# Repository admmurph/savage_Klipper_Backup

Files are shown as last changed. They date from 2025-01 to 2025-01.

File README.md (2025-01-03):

Backup for my Ender 3v2, currently mostly stock with a CR Touch w/stock metal bracket. Mostly small mods such as magnetic PEI plate, capricorn tube, and the mini satsana duct (remix) from thingiverse, with 0.6mm nozzle.

If you're setting up Klipper for the first time with an E3v2 4.2.2 Mainboard everything should be pretty dialed in. Can be adjusted for mostly any printer if you know what to change. Run a PID tune (see macros.cfg) for the bed,nozzle, as well as [input shaper] calibration, e-steps, and tune z offset (tune it, then tune current filament flow, then tune z offset again).
A few things should be changed/tuned in the slicer as well, i.e. pressure advance as well as retraction per filament. Included samples and links to useful tools and guides. See [firmware_retraction] and [extruder] pressure_advance in printer.cfg.

I highly recommend Orcaslicer (https://github.com/SoftFever/OrcaSlicer).

If you're setting up Klipper for the first time, use KIAUH (https://github.com/dw-0/kiauh). Very straightforward.

# Klipper-Backup 💾 

Klipper backup script for manual or automated GitHub backups. This backup is for Klipper+Moonraker, with Mainsail interface.

This backup is provided by [Klipper-Backup](https://github.com/Staubgeborener/klipper-backup).

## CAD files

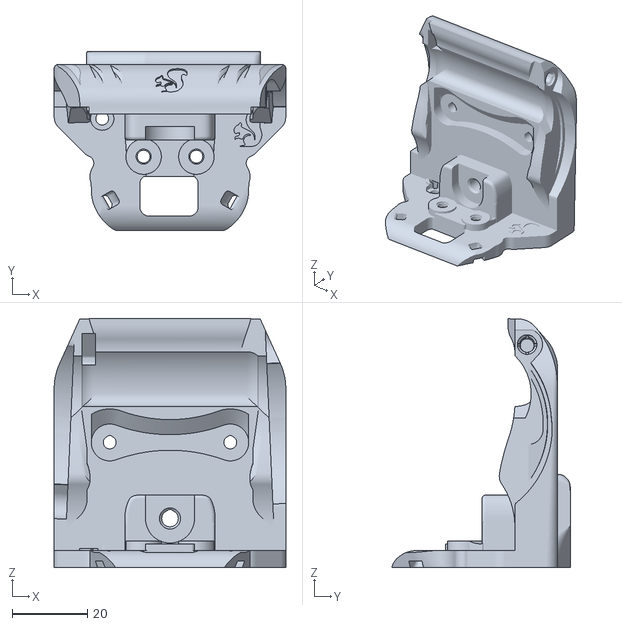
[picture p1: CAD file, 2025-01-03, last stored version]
printer_upgrades/ducts/apollo/Orbiter 2.x - front motor - Creality - stock MK8.stl
61.5 x 47.4 x 66.1

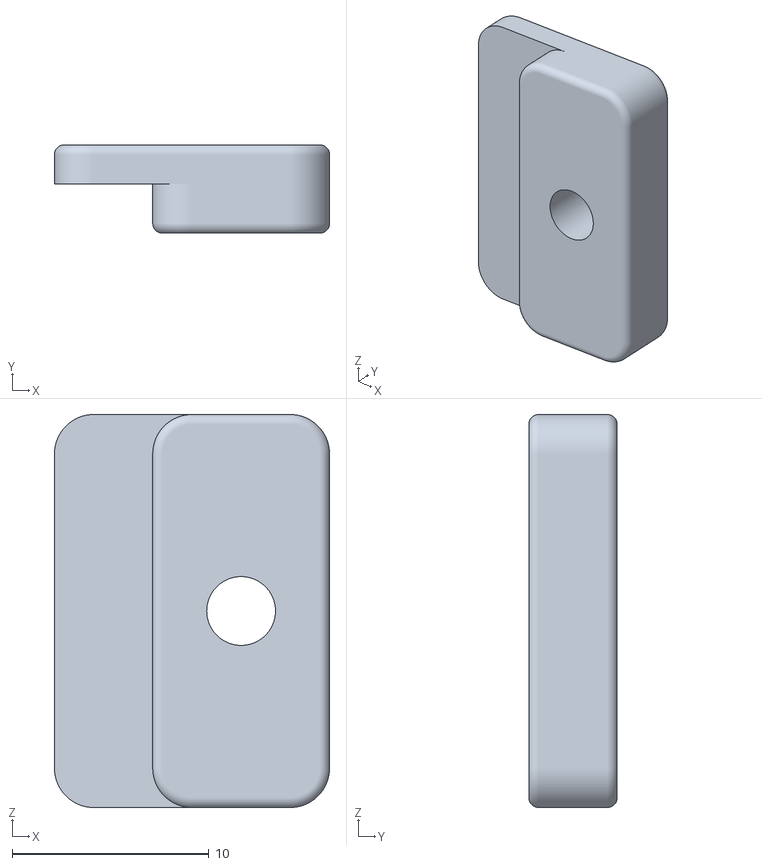
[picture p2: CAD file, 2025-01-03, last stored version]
printer_upgrades/ducts/MiniSatsana1x4010/mini_Satsana_Clamp.stl
14.0 x 4.50 x 20.0

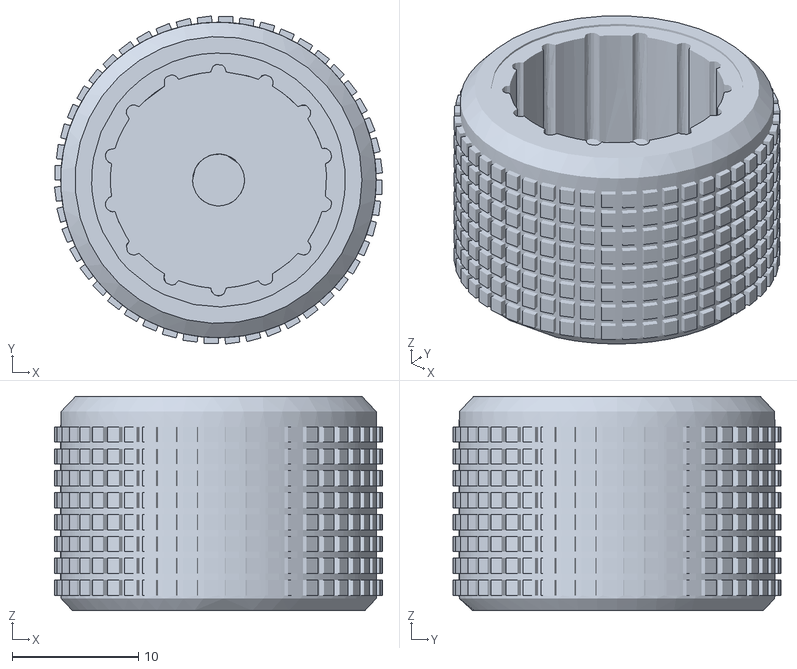
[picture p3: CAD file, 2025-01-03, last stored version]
printer_upgrades/extras/Knob_Belt_Tension_Covers.stl
26.0 x 26.0 x 17.0

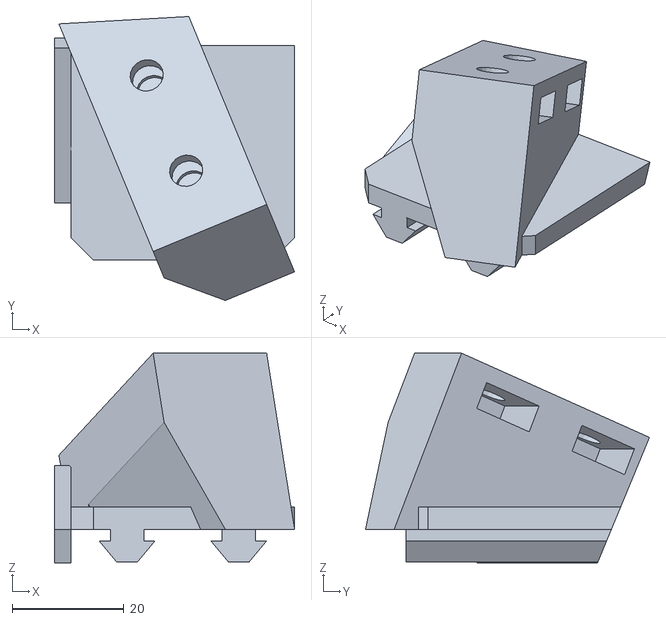
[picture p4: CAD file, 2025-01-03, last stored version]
printer_upgrades/filament_holders/Rear_angle_spool_holder.stl
43.0 x 50.8 x 37.5

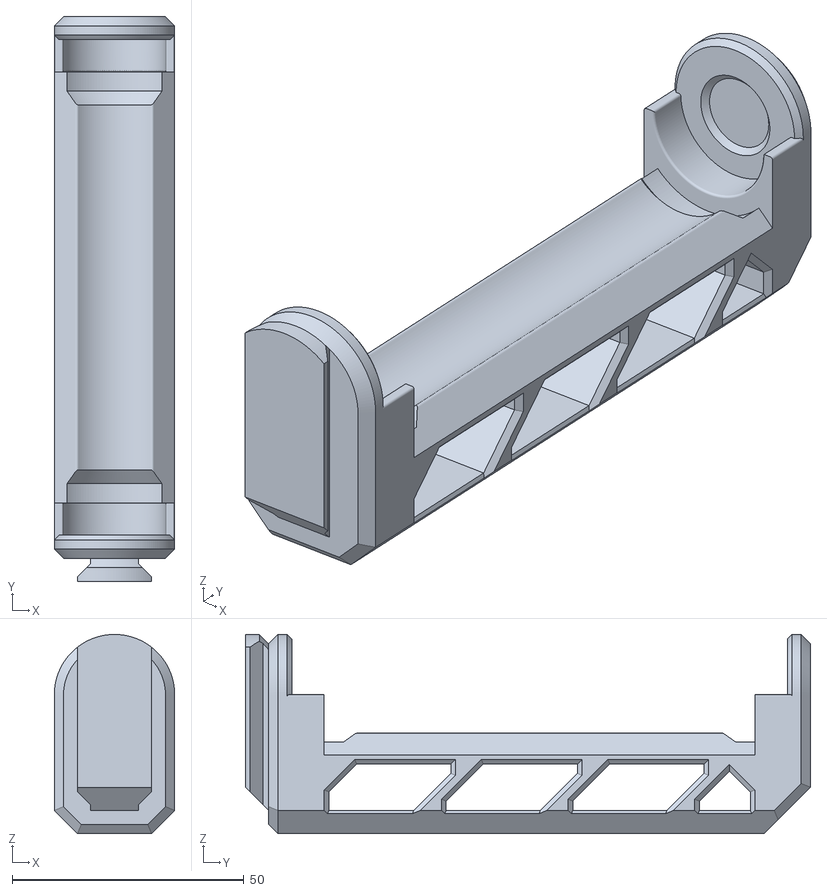
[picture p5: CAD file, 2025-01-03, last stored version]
printer_upgrades/filament_holders/Roller/Body_80mm.stl
26.0 x 122.0 x 43.0

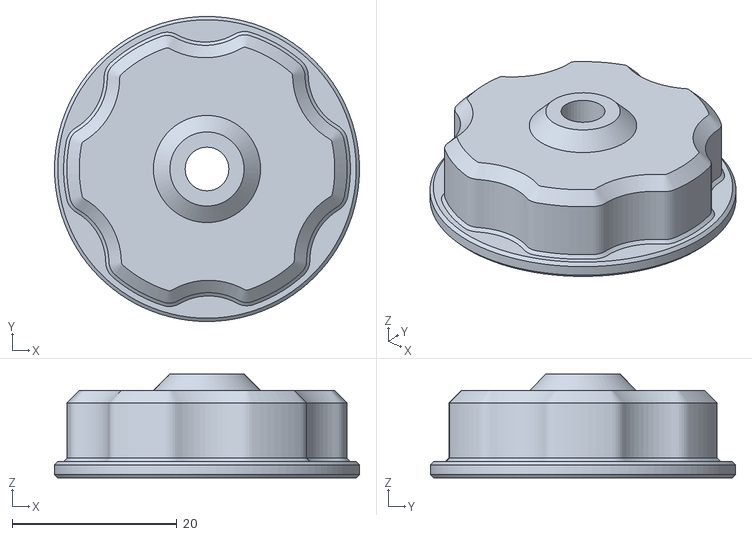
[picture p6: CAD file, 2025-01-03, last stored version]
printer_upgrades/kevinakasam_singleMotorBeltedZ/1_TensionerRing_V3.6.stl
37.0 x 37.0 x 12.6

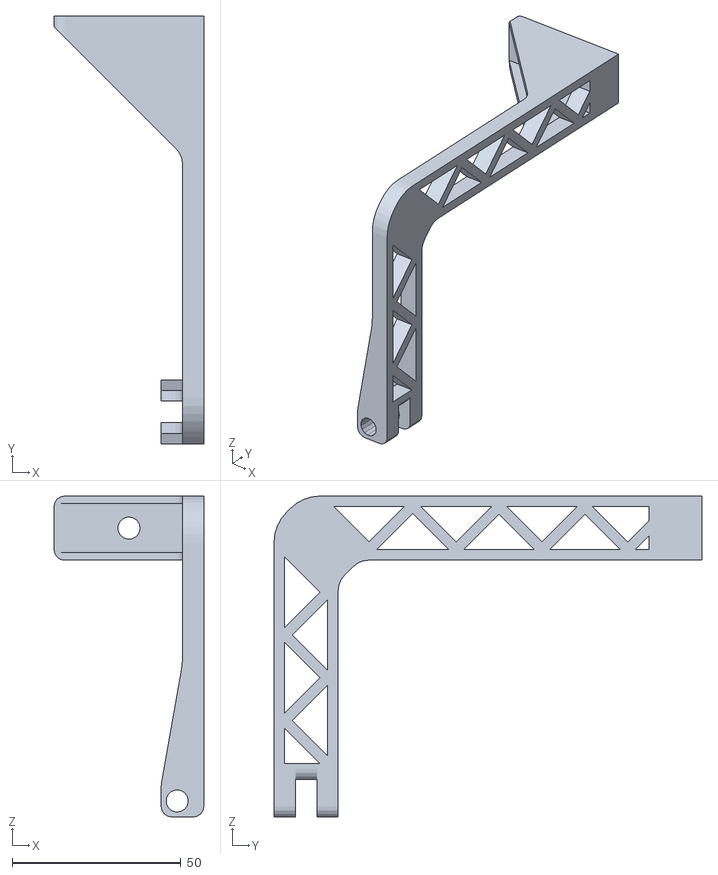
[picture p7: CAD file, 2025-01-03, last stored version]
printer_upgrades/m5_webcam_arms/Ender_3_Webcam_Arm_v2.stl
44.4 x 127.0 x 95.2

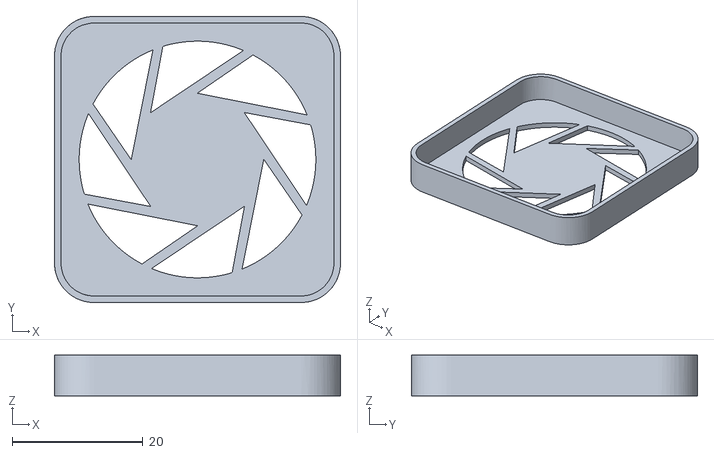
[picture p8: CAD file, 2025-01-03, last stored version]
printer_upgrades/qr_covers/Aperature_Science_Ender_3_Cover.stl
43.7 x 43.7 x 6.20

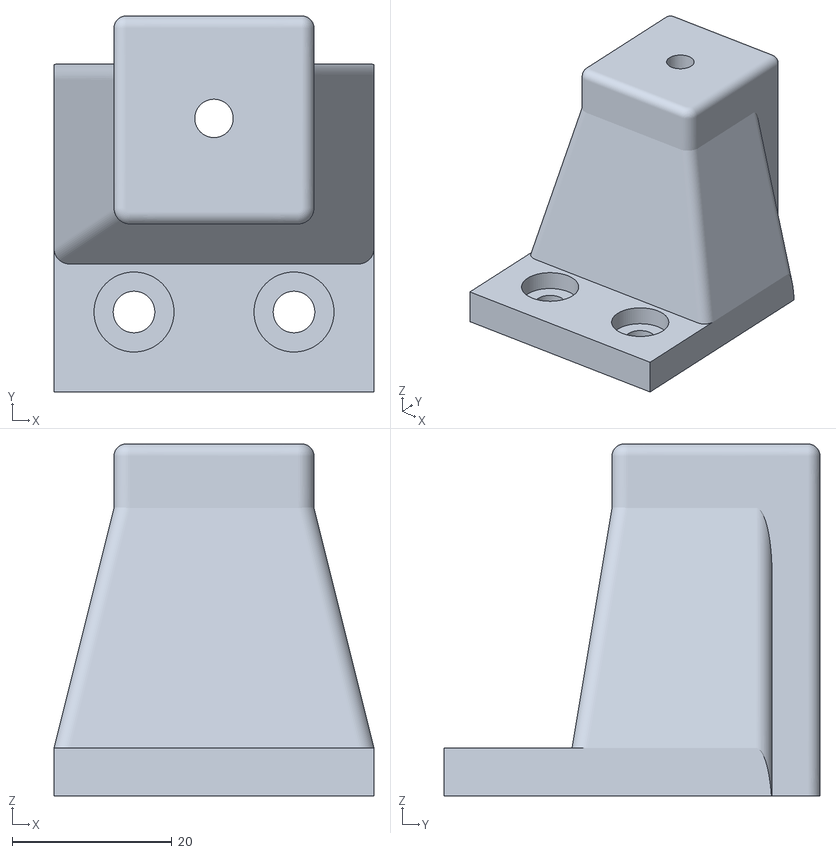
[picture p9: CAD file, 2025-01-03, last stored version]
printer_upgrades/replacement_parts/Ender3_V2_belt_tensionerY.stl
40.0 x 47.0 x 44.0

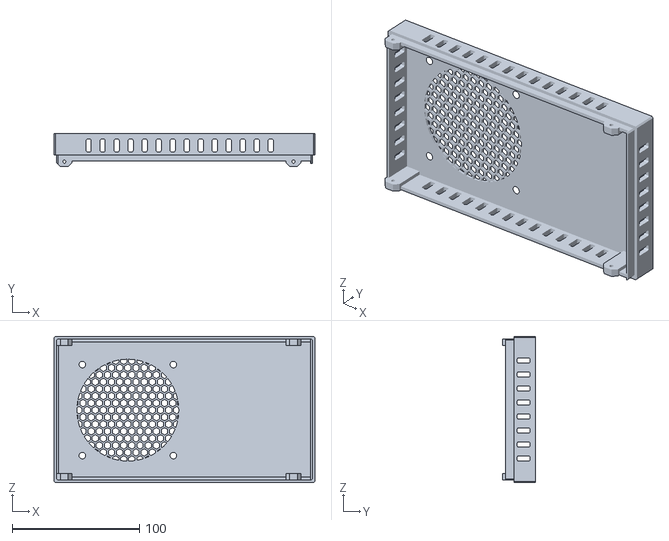
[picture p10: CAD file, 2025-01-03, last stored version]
printer_upgrades/undercarriage/PSU_cover_slim.stl
205.0 x 26.1 x 115.0

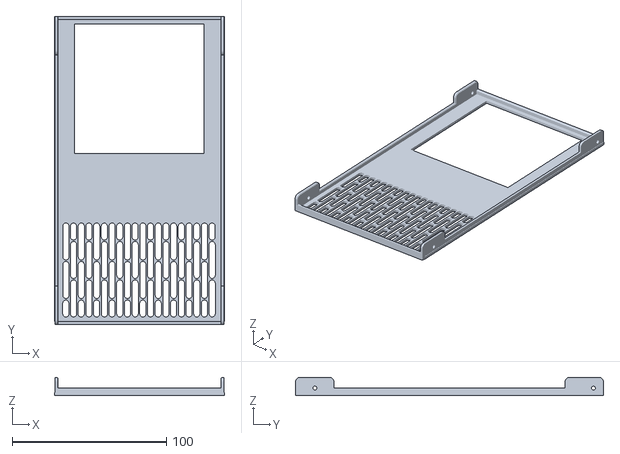
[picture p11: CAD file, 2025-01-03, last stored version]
printer_upgrades/undercarriage/slim80mm psu/Plaque.stl
110.6 x 200.0 x 12.0

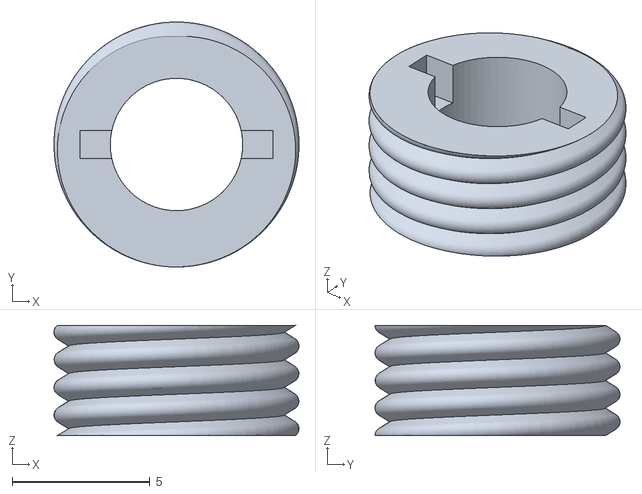
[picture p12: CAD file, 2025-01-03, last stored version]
printer_upgrades/ducts/apollo/Stock hotend cable guide.stl
8.88 x 8.88 x 4.00

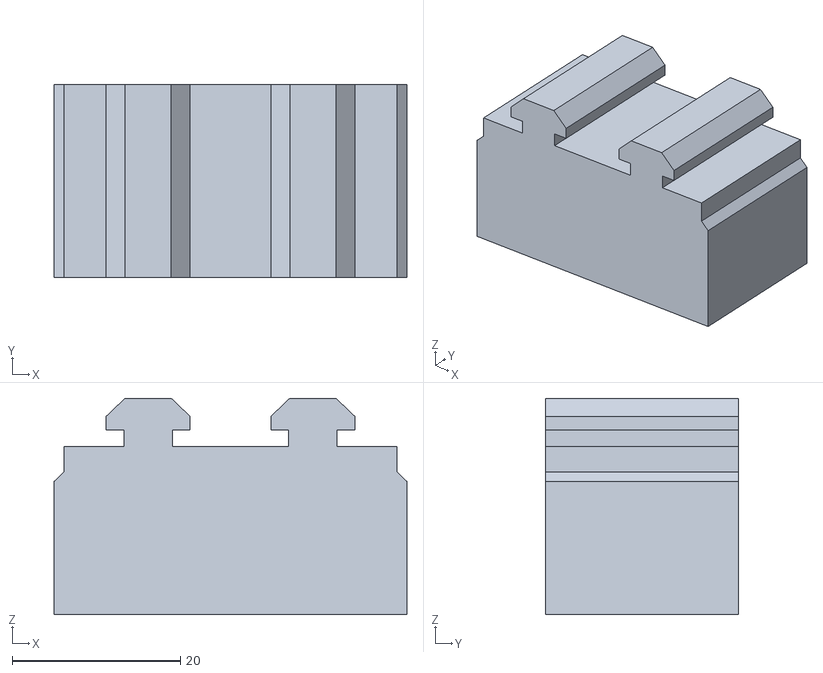
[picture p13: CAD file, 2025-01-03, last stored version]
printer_upgrades/extras/Feet_Riser_Solid.STL
42.0 x 23.0 x 25.8

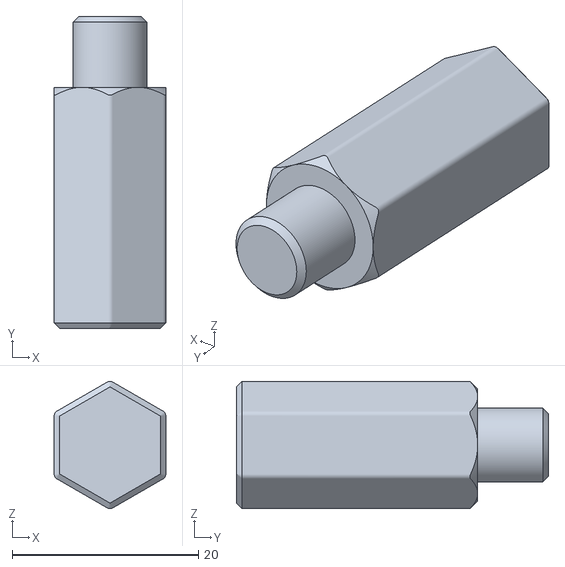
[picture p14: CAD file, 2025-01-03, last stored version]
printer_upgrades/filament_holders/Roller/Pin.stl
12.0 x 33.5 x 13.7

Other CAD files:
printer_upgrades/kevinakasam_singleMotorBeltedZ/2_Bottom_F623_V3.7.stl
printer_upgrades/m5_webcam_arms/Ender_3_Webcam_Base_v2.stl
printer_upgrades/qr_covers/Back_plate.stl
printer_upgrades/replacement_parts/Ender3_V2_belt_tensionerX.stl
printer_upgrades/ducts/apollo/CRtouch - baseline.stl
printer_upgrades/ducts/apollo/Orbiter 1.5 - Creality - stock MK8.stl
printer_upgrades/ducts/apollo/bowden adapter - orbiter 2 rear motor backplate.stl
printer_upgrades/ducts/apollo/left duct - baseline.stl
printer_upgrades/ducts/apollo/right duct - baseline.stl
printer_upgrades/extras/Ender 3 bed leveling wheel clips v2 thicker arms.stl
printer_upgrades/extras/Ender 3 bed leveling wheel clips v2 thicker armsflipped.stl
printer_upgrades/extras/MinimalBedHandle.stl
printer_upgrades/extras/chungy_knob.stl
printer_upgrades/filament_holders/Roller/Body_100mm.stl
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

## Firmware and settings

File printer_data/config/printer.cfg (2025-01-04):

[include mainsail.cfg]
[include macros.cfg]
[include KAMP_Settings.cfg] # adaptive purge
[include shell_command.cfg]
[exclude_object]
# See docs/Config_Reference.md for a description of parameters.
# 
# <---------------------- Ender 3v2 Config File ----------------------> #
# # by Adam Murphy
[printer]
kinematics: cartesian
max_velocity: 300
max_accel: 3000
max_accel_to_decel: 3000
max_z_velocity: 5
max_z_accel: 100
square_corner_velocity: 5

[heater_bed]
heater_pin: PA2
sensor_type: EPCOS 100K B57560G104F
sensor_pin: PC4
# Tuned for stock hardware with 50 degree Celsius target <- See macros.cfg
# control = pid
# pid_kp = 71.013
# pid_ki = 1.466
# pid_kd = 860.140
min_temp: 0
max_temp: 120

[extruder]
step_pin: PB4
dir_pin: PB3
enable_pin: !PC3
microsteps: 16
max_extrude_only_distance: 100.0 
rotation_distance: 33.1 # [https://ellis3dp.com/Print-Tuning-Guide/articles/extruder_calibration.html#steps]
nozzle_diameter: 0.400  # Change to current nozzle size!! <----
filament_diameter: 1.750
pressure_advance: 0.104 # See [firmware_retraction for per-filament example]
heater_pin: PA1
#   Stock hotend:
#sensor_type: EPCOS 100K B57560G104F
#   High Speed Print Head Upgrade Hotend Kit For 
#   Ender 3/CR10/VORON 2.4 Hi-End Extruder J-head:
sensor_type: Generic 3950
#   link: https://www.aliexpress.us/item/3256807991597019
sensor_pin: PC5
min_temp: 0
max_temp: 270
#control = pid #tuned for stock hotend @ 210°C
# pid_kp = 25.649
# pid_ki = 1.276
# pid_kd = 128.886
max_extrude_cross_section: 5 # Setting for KAMP Adaptive Purge

[firmware_retraction]
#   "Highlight + CTRL+/" to comment out if using slicer retraction
retract_length: 2
#   The length of filament (in mm) to retract when G10 is activated,
#   and to unretract when G11 is activated (but see
#   unretract_extra_length below). The default is 2 mm.
#   Very conservative value, accounting for pressure advance.
retract_speed: 30
#   The speed of retraction, in mm/s. The default is 30 mm/s.
unretract_extra_length: 0
#   The length (in mm) of *additional* filament to add when
#   unretracting.
unretract_speed: 40
#   The speed of unretraction, in mm/s. The default is 40 mm/s.
#
#   Retraction Test 
#   (Use the Orcaslicer Calibration tool. Adapt this command to the settings used):
#
#   TUNING_TOWER COMMAND=SET_RETRACTION PARAMETER=RETRACT_LENGTH START=0 FACTOR=0.1
#
#   Slicer filament gcode example:
#
# ; filament start gcode
# SET_PRESSURE_ADVANCE ADVANCE=?
# SET_RETRACTION RETRACT_LENGTH=? RETRACT_SPEED=? UNRETRACT_SPEED=? ;doesn't produce console response :(
# RESPOND MSG="retract_length: 0.0 | retract_speed: 0.0 | unretract_speed: 0.0"
# RESPOND MSG="...Printing with ?Color & Type? - ?Brand & Characteristics?" ; i.e. Black Rapid PETG - Elegoo Glossy 
#

[input_shaper]
shaper_freq_x:49.0196078431
shaper_freq_y:54.5851528384
#shaper_type: mvz
#  For testing: [https://www.klipper3d.org/Resonance_Compensation.html]
#  Will set up ADXL345 tuning soon, may be on another fork (if viewed later). 

# <---------------------- CR_Touch Config ----------------------> #
# This entire section can be removed/commented out (Highlight + CTRL+/) if using stock Z-endstop #

[bltouch]
sensor_pin: ^PB1  # This is unique to your mainboard
control_pin: PB0  # This is unique to your mainboard
x_offset: -51.6   # This may need to be calibrated
y_offset: -12.5      # This may need to be calibrated
#z_offset: 1.100   # Tune value 
# [https://ellis3dp.com/Print-Tuning-Guide/articles/first_layer_squish.html]
samples: 2       
speed: 2          

[safe_z_home] 
# Change coordinates to the center of your print bed (ATLEAST values larger than probe offset!!)
home_xy_position: 117, 100  # Nozzle is pretty centered 
speed: 70                   # Turn this down if z-offset isn't dialed in
z_hop: 10                   # Move up 10mm
z_hop_speed: 10             #

[bed_mesh] # Adaptive mesh enabled; EXCLUDE OBJECTS must be turned on in slicer!
# See [gcode_macro START_PRINT] in macros.cfg to enable/disable
# [https://www.klipper3d.org/Bed_Mesh.html]
# [https://www.klipper3d.org/Exclude_Object.html]
speed: 150
horizontal_move_z: 6
mesh_min: 20, 6       # These are fairly safe min/max values, 
mesh_max: 195.5, 207  # glass bed w/ metal clips should have no issue
probe_count: 5,5
mesh_pps: 2,2
fade_start: 1
fade_end: 10    # Stop using the bed mesh by z=10
fade_target: 0
adaptive_margin: 5

[screws_tilt_adjust]
# Easiest way to level the bed
# Values are for Ender 3v2 with CrTouch/w included steel bracket.
# [https://www.klipper3d.org/Manual_Level.html?h=z+endstop+c#adjusting-bed-leveling-screws-using-the-bed-probe]
screw1: 74, 199.5
screw1_name: rear left screw # Base screw
screw2: 74, 31.5
screw2_name: front left screw
screw3: 243,31.5
screw3_name: front right screw
screw4: 243,199.5
screw4_name: rear right screw
horizontal_move_z: 10
speed: 150
screw_thread: CW-M4

# Install with KIAUH or comment out:
[include moonraker_obico_macros.cfg]
# Black magic free web monitoring of printer. Free AI print failure detection. Free live webcam view. Useful but ?

# <---------------------- Stepper-Mainboard Config ----------------------> #
# Pretty much stock config (w/ less conservative x&y min/max values) + CR Touch
# This file contains pin mappings for the stock 2020 Creality Ender 3
# V2. To use this config, during "make menuconfig" select the
# STM32F103 with a "28KiB bootloader" and serial (on USART1 PA10/PA9)
# communication.

# If you prefer a direct serial connection, in "make menuconfig"
# select "Enable extra low-level configuration options" and select
# serial (on USART3 PB11/PB10), which is broken out on the 10 pin IDC
# cable used for the LCD module as follows:
# 3: Tx, 4: Rx, 9: GND, 10: VCC

# Flash this firmware by copying "out/klipper.bin" to a SD card and
# turning on the printer with the card inserted. The firmware
# filename must end in ".bin" and must not match the last filename
# that was flashed.

[mcu]
serial: /dev/serial/by-id/usb-1a86_USB_Serial-if00-port0
restart_method: command

[fan]
pin: PA0

[stepper_x]
step_pin: PC2
dir_pin: PB9
enable_pin: !PC3
microsteps: 16
rotation_distance: 40
endstop_pin: ^PA5
position_endstop: 0
position_min: -15
position_max: 245
homing_speed: 50

[stepper_y]
step_pin: PB8
dir_pin: PB7
enable_pin: !PC3
microsteps: 16
rotation_distance: 40
endstop_pin: ^PA6
position_endstop: 0
position_min: -13
position_max: 230
homing_speed: 50

[stepper_z]
step_pin: PB6
dir_pin: !PB5
enable_pin: !PC3
microsteps: 16
rotation_distance: 8
endstop_pin: probe:z_virtual_endstop
#position_endstop: 0.0 # CR TOUCH
position_max: 250
position_min: -6

# <---------------------- No need to edit ----------------------> #
[idle_timeout]
#   Idle time (in seconds) to wait before running the above G-Code
#   commands. The default is 600 seconds. Set via macros.cfg START_PRINT, PREHEAT and DRY_FILAMENT

[gcode_arcs]
resolution: 0.25 #lolz
#   An arc will be split into segments. Each segment's length will
#   equal the resolution in mm set above. Lower values will produce a
#   finer arc, but also more work for your machine. Arcs smaller than
#   the configured value will become straight lines. The default is
#   1mm.

# VVVV Automatic | Delete if having issues VVVV

#*# <---------------------- SAVE_CONFIG ---------------------->
#*# DO NOT EDIT THIS BLOCK OR BELOW. The contents are auto-generated.
#*#
#*# [heater_bed]
#*# control = pid
#*# pid_kp = 71.013
#*# pid_ki = 1.466
#*# pid_kd = 860.140
#*#
#*# [extruder]
#*# control = pid
#*# pid_kp = 36.670
#*# pid_ki = 14.380
#*# pid_kd = 23.377
#*#
#*# [bltouch]
#*# z_offset = 1.205

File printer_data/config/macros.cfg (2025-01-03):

[gcode_macro START_PRINT]
gcode:
# Orcaslicer start print machine g-code (activates this macro):
# START_PRINT BED_TEMP=[bed_temperature_initial_layer_single] EXTRUDER_TEMP=[nozzle_temperature_initial_layer] CHAMBER_TEMP=[chamber_temperature] #KEEP ALL ON ONE LINE!
#
  SET_IDLE_TIMEOUT TIMEOUT=1200
  TURN_OFF_HEATERS
  # Get first-layer bed-temp from slicer (Orca: [bed_temperature_initial_layer_single])
  {% set BED_TEMP = params.BED_TEMP|default(55)|float %}
  # Get first-layer extruder-temp from slicer (Orca: [nozzle_temperature_initial_layer])
  {% set EXTRUDER_TEMP = params.EXTRUDER_TEMP|default(190)|float %}
  M104 S{150} ; set nozzle warmup temp
  M140 S{BED_TEMP} ; wait for bed temp to create mesh
  RESPOND MSG="Homing and waiting for bed to reach temperature"
  G28 #home all
  M190 S{BED_TEMP} ; wait for bed temp to create mesh
  RESPOND MSG="Creating adaptive bed mesh"
  M104 S{EXTRUDER_TEMP} ; warmup while creating adaptive mesh
  BED_MESH_CALIBRATE PROFILE=currPrint Adaptive=1 Adaptive_Margin=5 PROBE_COUNT=4
  BED_MESH_PROFILE SAVE=currPrint
  BED_MESH_PROFILE LOAD=currPrint
  RESPOND MSG="Waiting for nozzle to reach temp... then drawing prime line"
  M109 S{EXTRUDER_TEMP} ; wait for temp to purge
  LINE_PURGE # purge nozzle
  RESPOND MSG="Print started!"
  
[gcode_macro END_PRINT]
gcode: 
# Orcaslicer end print machine g-code (activates this macro):
# ;Present model
# {if max_layer_z < printable_height}G1 Z{min(max_layer_z+2, printable_height)} F600 ; Move print head up{endif} 
# G1 X5 Y{print_bed_max[1]*0.8} F{travel_speed*60} ; present print
# {if max_layer_z < printable_height-10}G1 Z{min(max_layer_z+70, printable_height-10)} F600 ; Move print head further up{endif}
# {if max_layer_z < printable_height*0.6}G1 Z{printable_height*0.6} F600 ; Move print head further up{endif}
# END_PRINT
#
  M83 ; set to relative
  TURN_OFF_HEATERS
  M84 X Y E ; disable motors
  RESPOND MSG="Print complete!"

[gcode_macro CANCEL_PRINT]
gcode: 
  M83 ; set to relative
  TURN_OFF_HEATERS
  # Move nozzle away from print while retracting
  G91
  G1 X-2 Y-2 E-3 F300    # Raise nozzle by 25mm
  G1 Z25 F3000
  G90
  M84 X Y E ; disable motors
  RESPOND MSG="Print canceled!"
    
[gcode_macro PREHEAT_FILAMENT]
description: Preheats extruder and bed for PLA printing, extruder set to 150 to prevent filament leaking while homing etc
gcode:
  {% set EXTRUDER_TEMP = nozzle_temperature_initial_layer|default(150)|float %}
  {% set BED_TEMP = bed_temperature_initial_layer_single|default(60)|float %}
  M104 S{EXTRUDER_TEMP}
  M140 S{BED_TEMP}
  SET_IDLE_TIMEOUT TIMEOUT = 1200

[gcode_macro DRY_FILAMENT]
description: Allows for the heated print bed to act as an active dry box. Idle timeout 8hrs | PLA = 40-50 TPU 40-45 PETG = 60-65 ABS = 80 ASA = 80-85 NYLON = 85-90
gcode: 
  SET_IDLE_TIMEOUT TIMEOUT=28800 # 8 hour timeout
  TURN_OFF_HEATERS
  {%set BED_TEMP = params.BED_TEMP|default(40)|int %}
  M140 S{BED_TEMP}

[gcode_macro UNLOAD_FILAMENT]
description: Unloads Filament from extruder
gcode:
  {% if printer.extruder.temperature < 180 %}
    {action_respond_info("Extruder temperature too low")}
  {% else %}
    SAVE_GCODE_STATE NAME=UNLOAD_state
    {% set Z = params.Z|default(50)|int %}
    {% set axis_max = printer.toolhead.axis_maximum %}
    {% set pos = printer.toolhead.position %}
 
    {% set z_diff = axis_max.z - pos.z %}
    {% set z_safe_lift = [ Z, z_diff ] | min%}
 
    G91                   # relative positioning
    G0 Z{ z_safe_lift }
    # Reset extruder position
    G92 E0
    G1 E5.0 F300        # extrude a little
    G1 E-50 F{ 10 * 60 } # perform the unload
    G1 E-50 F{ 5 * 60 }   # finish the unload
    RESTORE_GCODE_STATE NAME=UNLOAD_state
  {% endif %}
  
# Good way to activate SCREWS_TILT_CALCULATE
  
[gcode_macro BED_TRAMMING_1]
description: Heats bed and starts process to level the bed with the screws
gcode:
  {% set BED_TEMP = params.BED_TEMP|default(60)|float %} 
  SET_HEATER_TEMPERATURE HEATER=heater_bed TARGET={BED_TEMP}
  HOME_CHECK
  M190 S{BED_TEMP}
  SCREWS_TILT_CALCULATE
  
[gcode_macro BED_TRAMMING_2]
description: Continues the bed screw leveling process (already heated)
gcode:
  SCREWS_TILT_CALCULATE

[gcode_macro G28]
# Only home if needed.
rename_existing: G28.1
gcode:
    {% if printer.toolhead.homed_axes != "xyz" %}
        G28.1
    {% endif %}

# Share variables between macros (Found this in someones macro.cfg but I don't really have a use for it yet)
# can be accessed via {printer["gcode_macro SHARE_VARIABLES"].VARIABLE_NAME}
# can be set with SET_GCODE_VARIABLE MACRO=SHARE_VARIABLES VARIABLE=VARIABLE_NAME VALUE=NEW_VALUE
[gcode_macro SHARE_VARIABLES]
variable_enable_save_config : False
variable_dim_enclosure_led : False
gcode:
#

#####################################
#          PID Tune Macros          #
#       Version 1.0  2023-1-30      #
#####################################

################################
######### PID_EXTRUDER #########
################################
[gcode_macro PID_EXTRUDER]
description: PID Tune for the Extruder
gcode:
  {% set e = printer.toolhead.extruder %}
  {% set T = params.TEMPERATURE|default(210)|float %}
  {% set S = params.FAN_IN_PERCENT|default(0)|float *2.55 %}
  {% set P = printer.configfile.config[e].pid_kp|float %}
  {% set I = printer.configfile.config[e].pid_ki|float %}
  {% set D = printer.configfile.config[e].pid_kd|float %}
  M106 S{S}
  M118 // PID parameters: pid_Kp={P} pid_Ki={I} pid_Kd={D}  (old)
  PID_CALIBRATE HEATER={e} TARGET={T}
  TURN_OFF_HEATERS
  SAVE_CONFIG
 
################################
############ PID_BED ###########
################################
[gcode_macro PID_BED]
description: PID Tune for the Bed
gcode:
  {% set T = params.TEMPERATURE|default(60)|float %}
  {% set P = printer.configfile.config['heater_bed'].pid_kp|float %}
  {% set I = printer.configfile.config['heater_bed'].pid_ki|float %}
  {% set D = printer.configfile.config['heater_bed'].pid_kd|float %}
  M118 // PID parameters: pid_Kp={P} pid_Ki={I} pid_Kd={D}  (old)
  PID_CALIBRATE HEATER=heater_bed TARGET={T}
  TURN_OFF_HEATERS
  SAVE_CONFIG

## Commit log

2024-12-27 New Backup on boot - 26/12/24 - 23:35:35
    [KAMP_Settings.cfg, macros.cfg, moonraker-obico-update.cfg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]
2024-12-27 printer.cfg modified - 27/12/24 - 00:09:57
    [printer.cfg]
2024-12-27 printer.cfg modified - 27/12/24 - 00:13:59
    [printer.cfg]
2024-12-27 printer.cfg modified - 27/12/24 - 00:14:38
    [printer.cfg]
2024-12-27 printer.cfg modified - 27/12/24 - 00:17:28
    [printer.cfg]
2024-12-27 printer.cfg modified - 27/12/24 - 00:19:22
    [printer.cfg]
2024-12-27 printer.cfg modified - 27/12/24 - 00:20:03
    [printer.cfg]
2024-12-27 printer.cfg modified - 27/12/24 - 02:46:23
    [printer.cfg]
2024-12-27 printer.cfg modified - 27/12/24 - 11:29:01
    [printer.cfg]
2024-12-27 printer.cfg modified - 27/12/24 - 13:32:06
    [printer.cfg]
2024-12-27 printer.cfg modified - 27/12/24 - 13:48:16
    [printer.cfg]
2024-12-28 printer.cfg modified - 28/12/24 - 00:16:36
    [printer.cfg]
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2024-12-28 config modified - 28/12/24 - 00:17:57
    [KAMP_Settings.cfg, macros.cfg, moonraker-obico-update.cfg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]
2024-12-28 exclude modified - 28/12/24 - 00:18:03
    [KAMP_Settings.cfg, macros.cfg, moonraker-obico-update.cfg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]
2024-12-28 main modified - 28/12/24 - 00:19:16
    [KAMP_Settings.cfg, macros.cfg, moonraker-obico-update.cfg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]
2024-12-28 heads modified - 28/12/24 - 00:19:22
    [KAMP_Settings.cfg, macros.cfg, moonraker-obico-update.cfg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]
2024-12-28 remotes modified - 28/12/24 - 00:19:40
    [KAMP_Settings.cfg, macros.cfg, moonraker-obico-update.cfg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]
2024-12-28 refs modified - 28/12/24 - 00:19:48
    [KAMP_Settings.cfg, macros.cfg, moonraker-obico-update.cfg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]
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2024-12-28 macros.cfg modified - 28/12/24 - 12:26:05
    [macros.cfg]
2024-12-28 macros.cfg modified - 28/12/24 - 13:31:59
    [macros.cfg]
2024-12-28 printer.cfg modified - 28/12/24 - 13:39:00
    [printer.cfg]
2024-12-28 macros.cfg modified - 28/12/24 - 13:44:15
    [macros.cfg]
2024-12-28 macros.cfg modified - 28/12/24 - 13:50:25
    [macros.cfg]
2024-12-28 macros.cfg modified - 28/12/24 - 14:55:38
    [macros.cfg]
2024-12-28 printer.cfg modified - 28/12/24 - 15:00:53
    [printer.cfg]
2024-12-29 macros.cfg modified - 29/12/24 - 00:45:51
    [macros.cfg]
2024-12-29 printer.cfg modified - 29/12/24 - 00:46:13
    [printer.cfg]
2024-12-29 macros.cfg modified - 29/12/24 - 00:49:34
    [macros.cfg]
2024-12-29 macros.cfg modified - 29/12/24 - 00:52:20
    [macros.cfg]
2024-12-29 macros.cfg modified - 29/12/24 - 00:55:26
    [macros.cfg]
2024-12-29 macros.cfg modified - 29/12/24 - 12:53:55
    [macros.cfg]
2025-01-02 printer.cfg modified - 02/01/25 - 12:09:52
    [printer.cfg]
2025-01-02 printer.cfg modified - 02/01/25 - 12:22:31
    [printer.cfg]
2025-01-03 macros.cfg modified - 02/01/25 - 16:06:14
    [macros.cfg]
2025-01-03 printer.cfg modified - 02/01/25 - 16:40:38
    [printer.cfg]
2025-01-03 printer.cfg modified - 02/01/25 - 16:45:29
    [printer.cfg]
2025-01-03 macros.cfg modified - 02/01/25 - 16:48:49
    [macros.cfg]
2025-01-03 printer.cfg modified - 02/01/25 - 16:54:48
    [printer.cfg]
2025-01-03 printer.cfg modified - 02/01/25 - 16:56:21
    [printer.cfg]
2025-01-03 printer.cfg modified - 02/01/25 - 16:58:55
    [printer.cfg]
2025-01-03 printer.cfg modified - 02/01/25 - 16:59:41
    [printer.cfg]
2025-01-03 macros.cfg modified - 02/01/25 - 17:04:23
    [macros.cfg]
2025-01-03 macros.cfg modified - 02/01/25 - 17:06:47
    [macros.cfg]
2025-01-03 printer.cfg modified - 02/01/25 - 17:23:26
    [printer.cfg]
2025-01-03 printer.cfg modified - 02/01/25 - 17:31:15
    [printer.cfg]
2025-01-03 printer.cfg modified - 02/01/25 - 17:36:45
    [printer.cfg]
2025-01-03 printer.cfg modified - 02/01/25 - 18:28:32
    [1_LeftTop_A_UL_V3.6.stl, 1_LeftTop_B_UL_V3.6.stl, 1_LeftV3.7.stl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]
2025-01-03 printer.cfg modified - 02/01/25 - 18:28:57
    [printer.cfg]
2025-01-03 printer.cfg modified - 03/01/25 - 00:54:44
    [printer.cfg]
2025-01-03 erm reset
    [1_LeftTop_A_UL_V3.6.stl, 1_LeftTop_B_UL_V3.6.stl, 1_LeftV3.7.stl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]
2025-01-04 printer.cfg modified - 03/01/25 - 20:04:58
    [printer.cfg]
2025-01-04 printer.cfg modified - 03/01/25 - 20:07:28
    [printer.cfg]
2025-01-04 printer.cfg modified - 03/01/25 - 20:09:00
    [printer.cfg]
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2025-01-04 printer.cfg modified - 03/01/25 - 20:10:03
    [printer.cfg]
2025-01-04 printer.cfg modified - 03/01/25 - 20:10:09
    [printer.cfg]
2025-01-04 printer.cfg modified - 03/01/25 - 20:10:20
    [printer.cfg]
2025-01-04 printer.cfg modified - 03/01/25 - 20:11:02
    [printer.cfg]
2025-01-04 printer.cfg modified - 03/01/25 - 20:11:25
    [printer.cfg]
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2025-01-04 printer_autosave.cfg modified - 03/01/25 - 20:21:07
    [printer.cfg]
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2025-01-04 printer_autosave.cfg modified - 03/01/25 - 20:27:50
    [printer.cfg]
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2025-01-04 printer.cfg modified - 03/01/25 - 20:31:25
    [printer.cfg]
2025-01-04 printer.cfg modified - 04/01/25 - 02:19:25
    [printer.cfg]
2025-01-04 printer.cfg modified - 04/01/25 - 02:23:16
    [printer.cfg]
2025-01-04 printer.cfg modified - 04/01/25 - 02:24:26
    [printer.cfg]
2025-01-04 printer_autosave.cfg modified - 04/01/25 - 02:24:39
    [printer.cfg]
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
